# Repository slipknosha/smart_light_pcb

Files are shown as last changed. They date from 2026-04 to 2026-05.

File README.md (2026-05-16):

# Smart Light PCB

KiCad hardware project for an ESP32-S3 BLE-controlled AC phase dimmer.

> [!WARNING]
> This project works with **220-230 VAC mains voltage**.
> Assembly, probing, flashing while connected to mains, and load testing require proper isolation, fusing, enclosure, and experience with high-voltage electronics.
> Treat this board as a prototype or lab project, not a certified consumer product.

## Related Repositories

The complete Smart Light project is split into two repositories:

- **PCB / KiCad hardware**: <https://github.com/slipknosha/smart_light_pcb/tree/develop>
- **ESP32-S3 firmware**: <https://github.com/slipknosha/smart_light/tree/develop>

This repository contains the schematic, PCB layout, BOM, 3D export, and manufacturing outputs.
The companion repository contains the ESP-IDF firmware that runs on this board.

## Project Overview

The board is a compact zero-cross synchronized triac dimmer built around an **ESP32-S3-WROOM-1** module.
It is designed to control a 220-230 VAC load using phase-angle dimming, with BLE control handled by firmware.

Main functional blocks:

- ESP32-S3 controller with native USB-C flashing
- Isolated AC/DC 5 V power supply based on Mean Well `IRM-05-5`
- 3.3 V logic rail generated by `LM1117MP-3.3`
- Zero-cross detector using `LTV-814`
- Random-phase optotriac driver using `MOC3052M`
- Main AC switching triac `BTB16-600B`
- BOOT and RESET buttons
- USB ESD protection and CC resistors
- AC input and load terminal blocks

## Firmware Compatibility

Use the firmware from:

<https://github.com/slipknosha/smart_light/tree/develop>

The current firmware expects this exact pin mapping:

| Board net | ESP32-S3 GPIO | Firmware module | Purpose |
|---|---:|---|---|
| `LTV_OUT` | `GPIO1` | `dimmer.c` | Zero-cross detector input |
| `MOC` | `GPIO2` | `dimmer.c` | Triac optodriver control output |
| `ESP_IO0` | `GPIO0` | Boot hardware | Bootloader button |
| `ESP_EN` | `EN` | Reset hardware | Reset / enable |
| `ESP_D-` | `USB_D-` / `GPIO19` | ESP-ROM / USB CDC | Native USB D- |
| `ESP_D+` | `USB_D+` / `GPIO20` | ESP-ROM / USB CDC | Native USB D+ |

The BLE device name is:

```text
SmartLight
```

The firmware exposes a custom BLE service and characteristic for dimming:

```text
Service:        7b5e0001-4c3f-4b3d-9a57-8d47b4ef0001
Characteristic: 7b5e0002-4c3f-4b3d-9a57-8d47b4ef0001
```

The characteristic accepts a binary little-endian unsigned integer in the range:

```text
0..100000
```

Typical nRF Connect writes:

```text
0      -> 00 00 00 00
1000   -> E8 03 00 00
10000  -> 10 27 00 00
50000  -> 50 C3 00 00
100000 -> A0 86 01 00
```

## Hardware Architecture

### Power Input and Rails

The board can receive 5 V from USB-C during development.
For standalone operation, the mains input feeds the isolated `IRM-05-5` AC/DC module.

Power chain:

```text
AC_L / AC_N -> IRM-05-5 -> 5 V -> LM1117MP-3.3 -> 3.3 V logic
```

The 5 V rail includes Schottky diode OR-ing/protection and decoupling capacitors.
The 3.3 V rail powers the ESP32-S3 and the low-voltage optocoupler side.

### Zero-Cross Detector

The zero-cross detector uses:

- `U1` - `LTV-814`
- `R1`, `R2` - 100 k mains-side resistors
- `R8` - 47 k pull-up on `LTV_OUT`

The isolated output is connected to `ESP32-S3 GPIO1` as `LTV_OUT`.
Firmware counts the accepted zero-cross edges and schedules the triac gate pulse relative to each half-cycle.

### Triac Driver

The triac gate path uses:

- `U3` - `MOC3052M` random-phase optotriac
- `Q2` - `BC847B` NPN transistor
- `R10` - 2.2 k base resistor
- `R11` - 100 k base pulldown
- `R3` - 180 ohm gate-side resistor
- `R12` - 330 ohm triac-side resistor
- `Q1` - `BTB16-600B` power triac

The ESP32 drives net `MOC` on `GPIO2`.
The firmware keeps this output low normally and sends a short pulse after each zero-cross delay.

### USB and Programming

The ESP32-S3 is wired for native USB flashing through `J3` USB-C.

USB-related parts:

- `J3` - USB-C receptacle
- `R4`, `R5` - 5.1 k CC resistors
- `U5` - `USBLC6-2SC6` ESD protection
- `SW2` - BOOT button on `ESP_IO0`
- `SW1` - RESET button on `ESP_EN`
- `J4` - 2x3 debug/programming header

The board can be flashed directly over USB without an external USB-UART converter.

## Connectors

| Connector | Label | Function |
|---|---|---|
| `J1` | `220V` | AC mains input, `AC_L` / `AC_N` |
| `J2` | `Load` | Switched AC load output |
| `J3` | USB-C | USB power and native ESP32-S3 flashing |
| `J4` | 2x3 header | `ESP_EN`, `TX`, `RX`, `ESP_IO0`, 3.3 V, GND |

## Key Components

| Reference | Part | Function |
|---|---|---|
| `U2` | `ESP32-S3-WROOM-1` | Main MCU / BLE controller |
| `PS1` | `IRM-05-5` | Isolated 5 V AC/DC supply |
| `U6` | `LM1117MP-3.3` | 3.3 V linear regulator |
| `U1` | `LTV-814` | Zero-cross optocoupler |
| `U3` | `MOC3052M` | Random-phase optotriac driver |
| `Q1` | `BTB16-600B` | Main AC triac |
| `Q2` | `BC847B` | MOC LED driver transistor |
| `U5` | `USBLC6-2SC6` | USB ESD protection |
| `F1` | Polyfuse | USB 5 V protection |

## Repository Structure

```text
smart_light_pcb/
├── README.md
├── LICENSE
├── sn.kicad_pro          # KiCad project
├── sn.kicad_sch          # schematic
├── sn.kicad_pcb          # PCB layout
├── sn.step               # exported 3D model
├── production/
│   ├── bom.csv           # bill of materials
│   ├── designators.csv
│   ├── netlist.ipc
│   ├── positions.csv     # pick-and-place
│   └── sn.zip            # Gerber + drill package
├── jlcpcb/
│   └── project.db
├── Snapeda.kicad_sym
├── Snapeda.pretty/
├── Snapeda.3dshapes/
└── sn-backups/
```

## Manufacturing Outputs

The `production/` directory contains files for fabrication and assembly:

- Gerber/drill archive: `production/sn.zip`
- BOM: `production/bom.csv`
- Pick-and-place: `production/positions.csv`
- IPC netlist: `production/netlist.ipc`
- Designator list: `production/designators.csv`

Review and regenerate these files after any schematic or PCB change before ordering.

## Suggested Bring-Up

1. Inspect the assembled PCB for shorts, solder bridges, and component orientation.
2. Power from USB only; verify 5 V and 3.3 V rails.
3. Confirm ESP32-S3 native USB flashing.
4. Flash the firmware from the companion repository.
5. Confirm BLE advertising as `SmartLight`.
6. Pair/bond from nRF Connect or the Android app.
7. Verify `LTV_OUT` zero-cross logs with mains connected under controlled conditions.
8. Test dimming with a suitable resistive load.
9. Move to real lamp testing only after the low-voltage and isolation checks pass.

## Safety Notes

- Keep the low-voltage USB/debug side isolated from mains during testing.
- Do not touch or probe the board while it is energized from AC.
- Use a safe enclosure and strain relief before any practical use.
- Check creepage/clearance and local electrical requirements before considering real deployment.
- The triac is non-isolated and may require thermal management depending on load current.

## License

This project is licensed under the **MIT License**.
See [LICENSE](LICENSE) for details.

## Author

**Vladyslav Bobrykov**

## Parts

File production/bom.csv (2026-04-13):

Designator | Footprint | Quantity | Value | LCSC Part #
C1, C10, C3, C8 | 0603 | 4 | 100n | C14663
C2 | CP_Elec_6.3x5.4 | 1 | 100uF | C134801
C4, C5 | 0805 | 2 | 22u | C45783
C6 | 0603 | 1 | 1u | C15849
C7 | 0603 | 1 | 10u | C19702
C9 | CP_Elec_6.3x5.4 | 1 | 100uF
D1, D3 | D_DO-41_SOD81_P10.16mm_Horizontal | 2 | 1N5817
D2, D4 | D_SOD-923 | 2 | ESD3.3
F1 | 1206 | 1 | Polyfuse
J1 | TerminalBlock_Phoenix_MKDS-1,5-2_1x02_P5.00mm_Horizontal | 1 | 220V
J2 | TerminalBlock_Phoenix_MKDS-1,5-2_1x02_P5.00mm_Horizontal | 1 | Load
J3 | USB_C_Receptacle_GCT_USB4085 | 1 | USB_C_Receptacle_USB2.0_16P
J4 | Pins_2x03_2.54mm_TH | 1 | Conn_02x03
L1, L2 | 0603 | 2 | 220Ohm
PS1 | Converter_ACDC_MeanWell_IRM-05-xx_THT | 1 | IRM-05-5
Q1 | TO-220-3_Vertical | 1 | BTB16-600B
Q2 | SOT-23 | 1 | BC847B | C57668
R1, R2 | R_Axial_DIN0207_L6.3mm_D2.5mm_P10.16mm_Horizontal | 2 | 100k
R10 | 0603 | 1 | 2.2k | C4190
R11 | 0603 | 1 | 100k | C25803
R12 | R_Axial_DIN0207_L6.3mm_D2.5mm_P10.16mm_Horizontal | 1 | 330
R3 | R_Axial_DIN0207_L6.3mm_D2.5mm_P10.16mm_Horizontal | 1 | 180
R4, R5 | 0603 | 2 | 5.1K | C23186
R6, R7 | 0603 | 2 | 10k | C25804
R8 | 0603 | 1 | 47k | C25819
R9 | 0603 | 1 | 120 | C22787
SW1 | SW_Push_1P1T_NO_E-Switch_TL3301NxxxxxG | 1 | RESET
SW2 | SW_Push_1P1T_NO_E-Switch_TL3301NxxxxxG | 1 | BOOT
U1 | DIP-4_W7.62mm | 1 | LTV-814
U2 | ESP32-S3-WROOM-1 | 1 | ESP32-S3-WROOM-1 | C2913198
U3 | DIP-6_W7.62mm | 1 | MOC3052M
U5 | SOT-23-6 | 1 | USBLC6-2SC6 | C7519
U6 | SOT-223-3_TabPin2 | 1 | LM1117MP-3.3 | C3750685

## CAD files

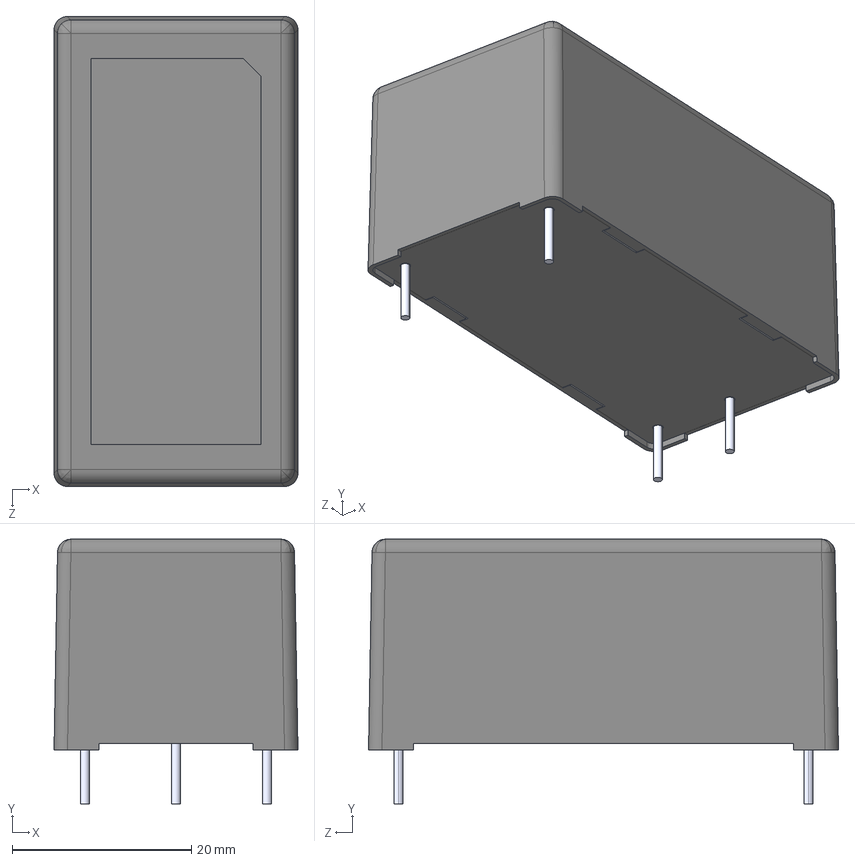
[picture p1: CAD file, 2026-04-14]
TMPS 15-105--3DModel-STEP-1.STEP
27.2 x 29.5 x 52.4 mm

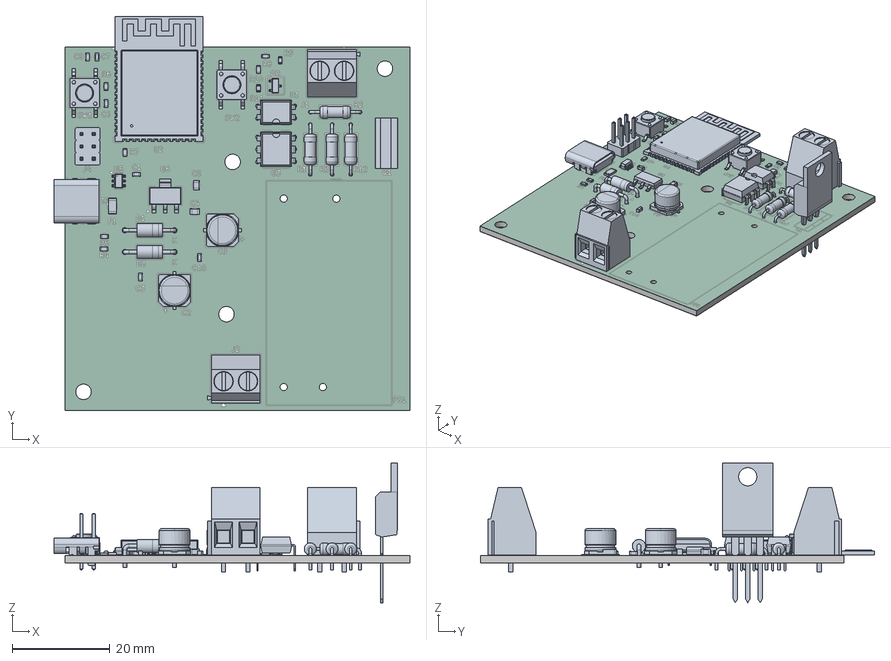
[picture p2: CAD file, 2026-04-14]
sn.step
72.7 x 80.5 x 28.5 mm
DIP-4_W7.62mm
R_0603_1608Metric x 8
R_Axial_DIN0207_L6.3mm_D2.5mm_P10.16mm_Horizontal x 4
D_DO-41_SOD81_P10.16mm_Horizontal x 2
C_0603_1608Metric x 6
PinHeader_2x03_P2.54mm_Vertical
TerminalBlock_Phoenix_MKDS-1,5-2_1x02_P5.00mm_Horizontal x 2
USB_C_Receptacle_GCT_USB4085
SOT-23
SW_Push_1P1T_NO_E-Switch_TL3301NxxxxxG x 2
CP_Elec_6.3x5.4 x 2
SOT-23-6
ESP32-S3-WROOM-1
DIP-6_W7.62mm
Fuse_1206_3216Metric
C_0805_2012Metric x 2
SOT-223
TO-220-3_Vertical
sn_silkscreen x 2
sn_soldermask x 2
sn_PCB

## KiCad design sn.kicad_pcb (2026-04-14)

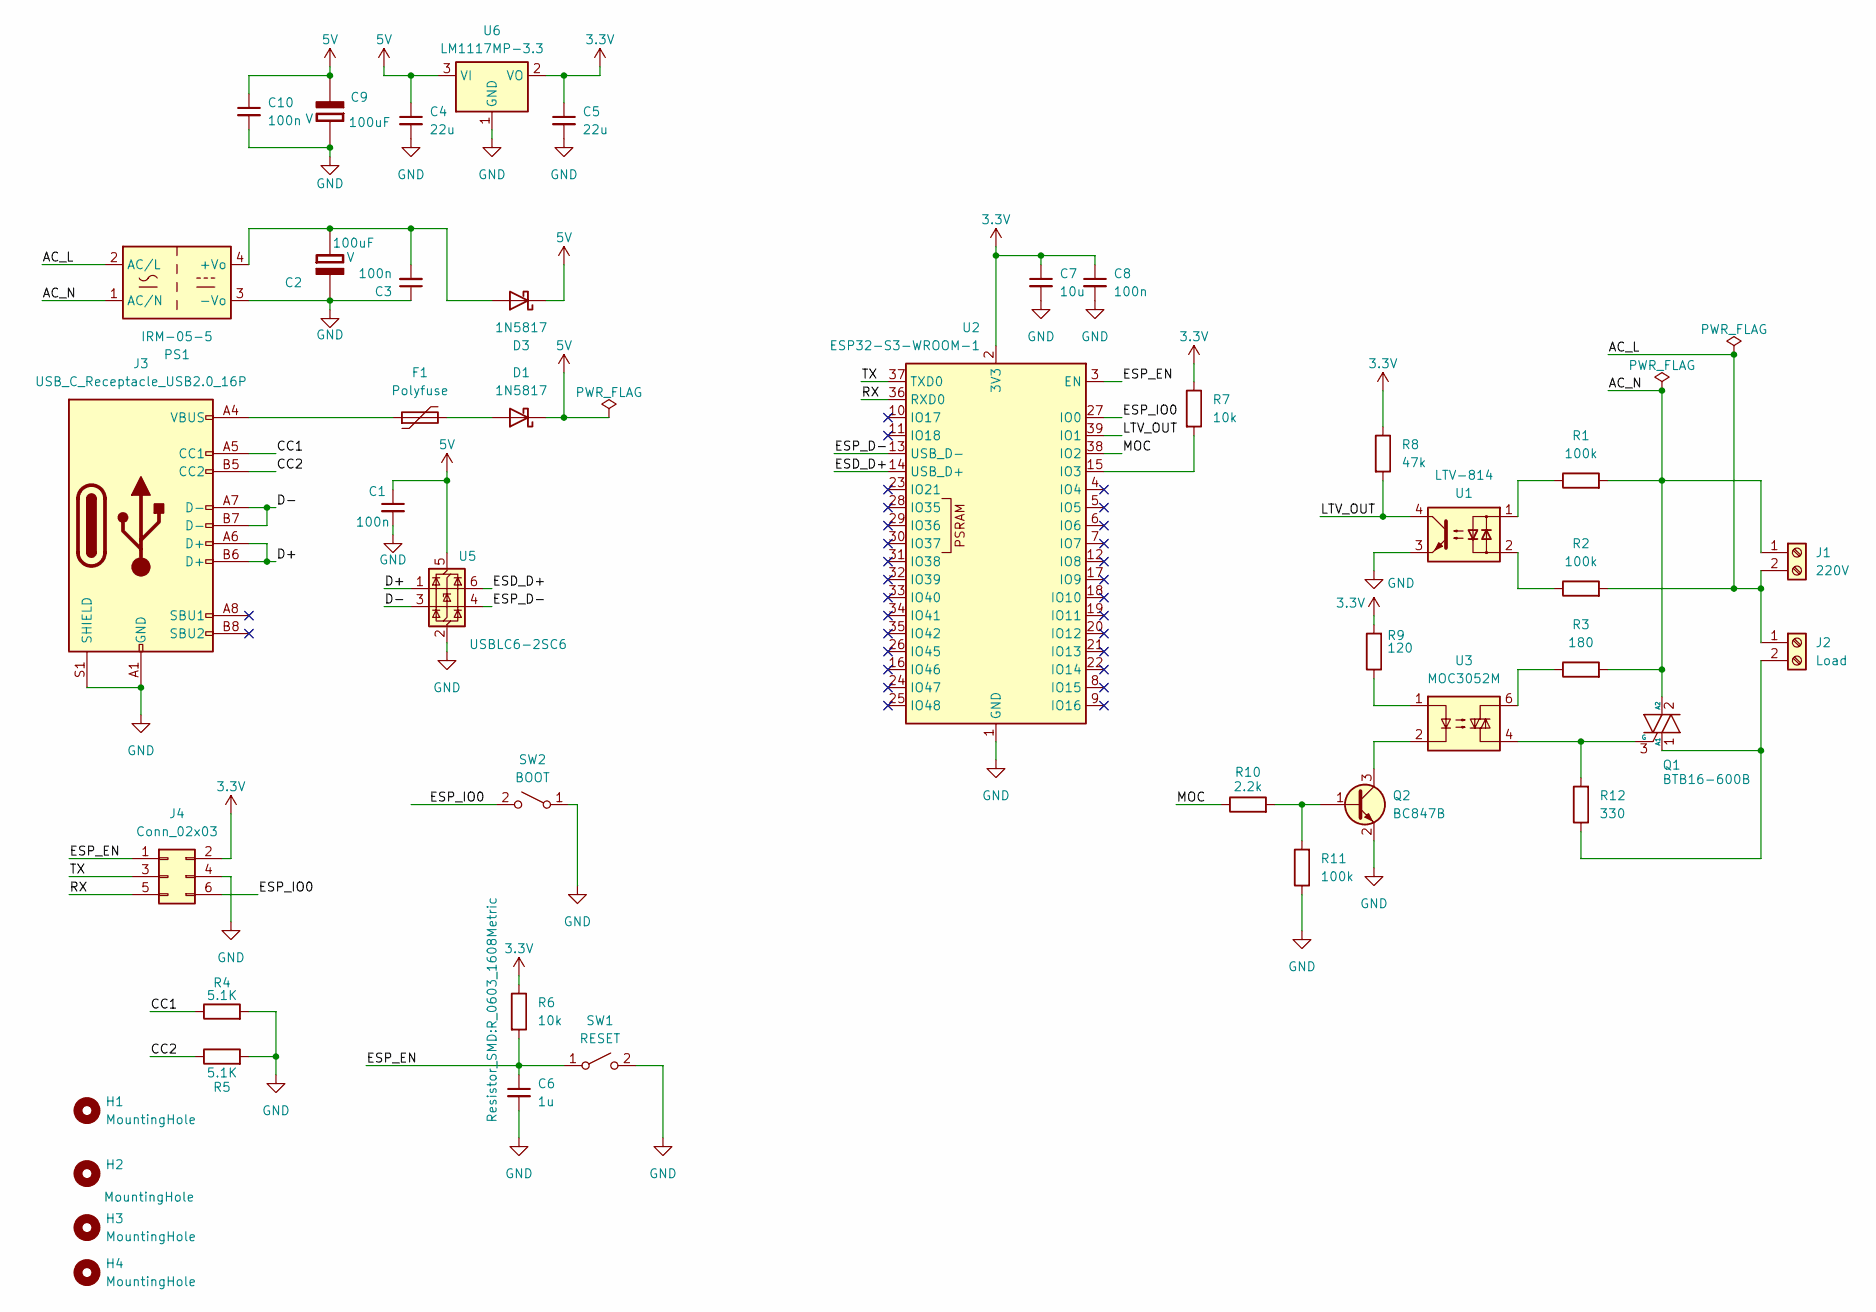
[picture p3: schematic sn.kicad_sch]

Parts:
C1, C3, C8, C10: 100n; C_0603_1608Metric
C2, C9: 100uF; CP_Elec_6.3x5.4; Rating V
C4, C5: 22u; C_0805_2012Metric
C6: 1u; C_0603_1608Metric
C7: 10u; C_0603_1608Metric
D1, D3: 1N5817; D_DO-41_SOD81_P10.16mm_Horizontal
F1: Polyfuse; Fuse_1206_3216Metric
H1, H2, H3, H4: MountingHole; MountingHole_3.2mm_M3
J1: 220V; TerminalBlock_Phoenix_MKDS-1,5-2_1x02_P5.00mm_Horizontal
J2: Load; TerminalBlock_Phoenix_MKDS-1,5-2_1x02_P5.00mm_Horizontal
J3: USB_C_Receptacle_USB2.0_16P; USB_C_Receptacle_GCT_USB4085
J4: Conn_02x03; Pins_2x03_2.54mm_TH; Part Number LL1009-2A, 2.54MM 2*3PIN HEADER,LENGTH=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
PS1: IRM-05-5; Converter_ACDC_MeanWell_IRM-05-xx_THT
Q1: BTB16-600B; TO-220-3_Vertical
Q2: BC847B; SOT-23
R1, R2: 100k; R_Axial_DIN0207_L6.3mm_D2.5mm_P10.16mm_Horizontal
R3: 180; R_Axial_DIN0207_L6.3mm_D2.5mm_P10.16mm_Horizontal
R4, R5: 5.1K; R_0603_1608Metric
R6, R7: 10k; R_0603_1608Metric
R8: 47k; R_0603_1608Metric
R9: 120; R_0603_1608Metric
R10: 2.2k; R_0603_1608Metric
R11: 100k; R_0603_1608Metric
R12: 330; R_Axial_DIN0207_L6.3mm_D2.5mm_P10.16mm_Horizontal
SW1: RESET; SW_Push_1P1T_NO_E-Switch_TL3301NxxxxxG
SW2: BOOT; SW_Push_1P1T_NO_E-Switch_TL3301NxxxxxG
U1: LTV-814; DIP-4_W7.62mm
U2: ESP32-S3-WROOM-1
U3: MOC3052M; DIP-6_W7.62mm
U5: USBLC6-2SC6; SOT-23-6
U6: LM1117MP-3.3; SOT-223-3_TabPin2

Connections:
3.3V: C5.1, C7.1, C8.1, J4.2 (+12V), R6.1, R7.1, R8.1, R9.2, U2.2 (3V3), U6.2 (VO)
5V: C1.1, C4.1, C9.2 (-), C10.1, D1.1 (K), D3.1 (K), U5.5 (VBUS), U6.3 (VI)
/AC_L: J1.2, J2.1, PS1.2 (AC/L), R2.2
/AC_N: J1.1, PS1.1 (AC/N), Q1.2 (A2), R1.2, R3.2
/CC1: J3.A5 (CC1), R4.1
/CC2: J3.B5 (CC2), R5.1
/D+: J3.A6 (D+), J3.B6 (D+), U5.1 (I/O1)
/D-: J3.A7 (D-), J3.B7 (D-), U5.3 (I/O2)
/ESD_D+: U2.14 (USB_D+), U5.6 (I/O1)
/ESP_D-: U2.13 (USB_D-), U5.4 (I/O2)
/ESP_EN: C6.1, J4.1 (+12V), R6.2, SW1.1 (A), U2.3 (EN)
/ESP_IO0: J4.6 (GND), SW2.2 (B), U2.27 (IO0)
/LTV_OUT: R8.2, U1.4, U2.39 (IO1)
/MOC: R10.1, U2.38 (IO2)
/RX: J4.5 (GND), U2.36 (RXD0)
/TX: J4.3 (GND), U2.37 (TXD0)
GND: C1.2, C2.2 (-), C3.1, C4.2, C5.2, C6.2, C7.2, C8.2, C9.1 (+), C10.2, J3.A1 (GND), J3.A12 (GND), J3.B1 (GND), J3.B12 (GND), J3.S1 (SHIELD), J4.4 (GND), PS1.3 (-Vo), Q2.2 (E), R4.2, R5.2, R11.1, SW1.2 (B), SW2.1 (A), U1.3, U2.1 (GND), U2.40 (GND), U2.41 (GND), U5.2 (GND), U6.1 (GND)
unnamed: C2.1 (+), C3.2, D3.2 (A), PS1.4 (+Vo)
unnamed: D1.2 (A), F1.2
unnamed: F1.1, J3.A4 (VBUS), J3.A9 (VBUS), J3.B4 (VBUS), J3.B9 (VBUS)
unnamed: J2.2, Q1.1 (A1), R12.1
unnamed: Q1.3 (G), R12.2, U3.4
unnamed: Q2.1 (B), R10.2, R11.2
unnamed: Q2.3 (C), U3.2
unnamed: R1.1, U1.1
unnamed: R2.1, U1.2
unnamed: R3.1, U3.6
unnamed: R9.1, U3.1
unnamed: R7.2, U2.15 (IO3)

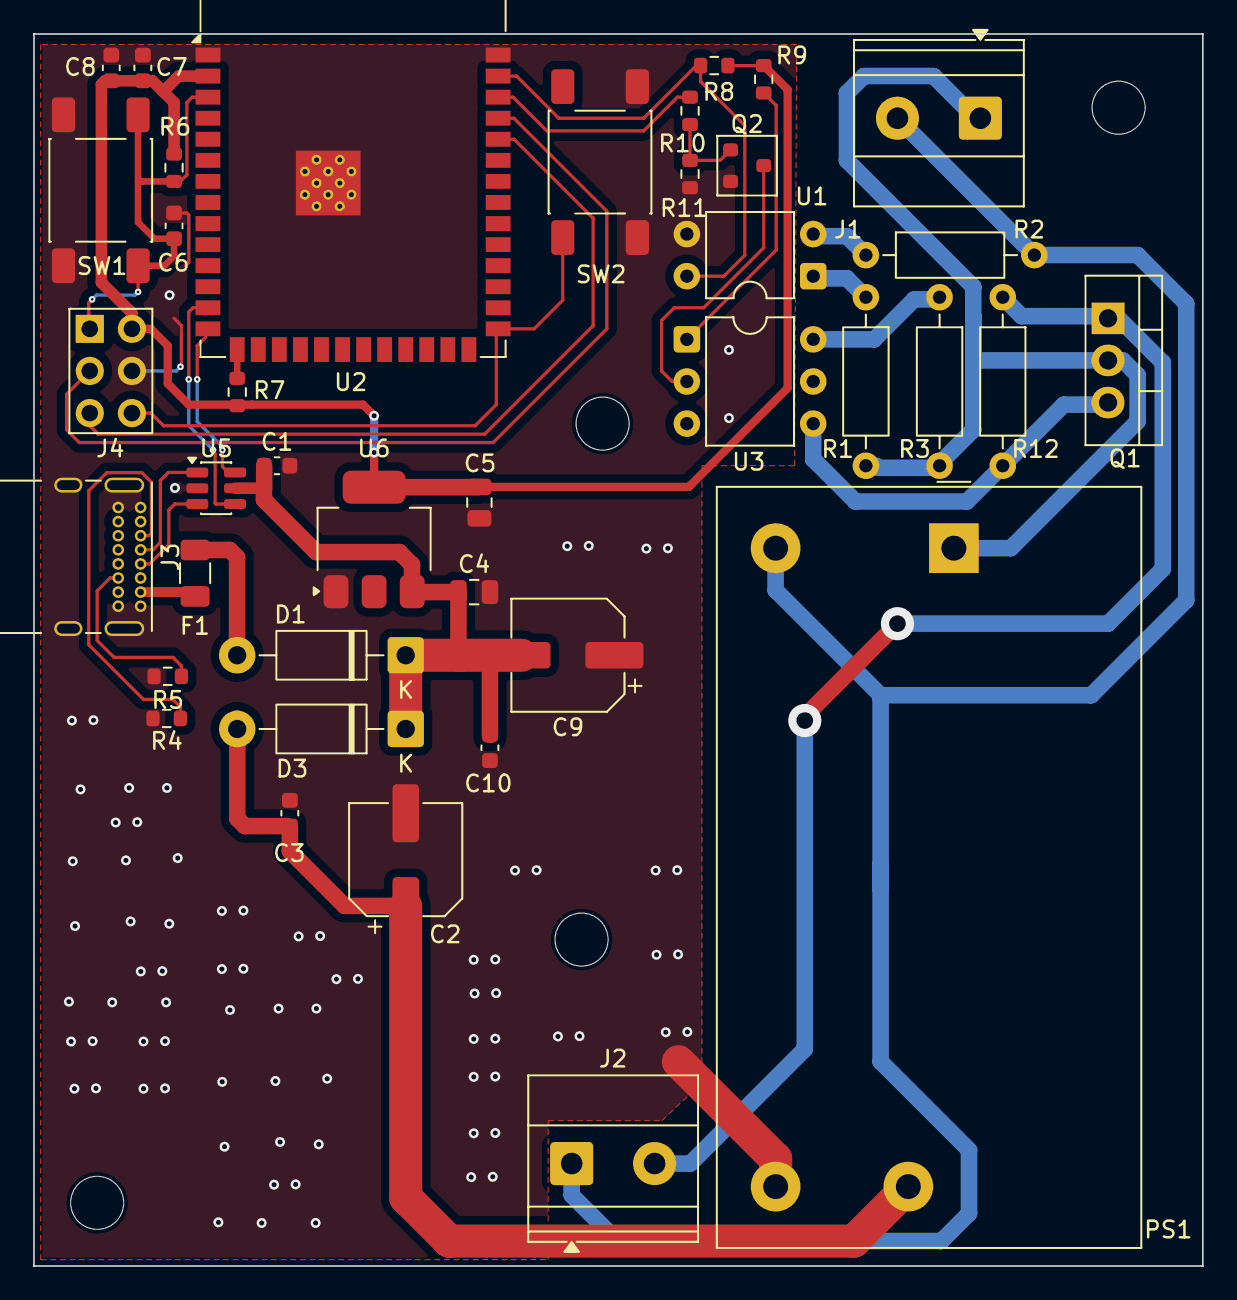
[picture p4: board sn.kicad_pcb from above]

Board: 2 copper layers, 70.5 x 74.3 mm, 43 parts (0 on the bottom side), 29 nets.

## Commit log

2026-04-07 add desing of PCB of AC dimmer
    [sn.kicad_pcb, sn.kicad_sch]
2026-04-08 redesing pcb
    [sn.kicad_pcb]
2026-04-13 add ASM
    [sn.kicad_pcb]
2026-04-13 remove l1 l2 d4 d2
    [bom.csv, designators.csv, positions.csv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]
2026-04-13 return tht type-c
    [BOM-sn.csv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]
2026-04-14 fix according review from JLCPCB
    [TMPS 15-105--3DModel-STEP-1.STEP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]
